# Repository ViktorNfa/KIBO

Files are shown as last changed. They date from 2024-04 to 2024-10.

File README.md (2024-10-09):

# KIBO Robot

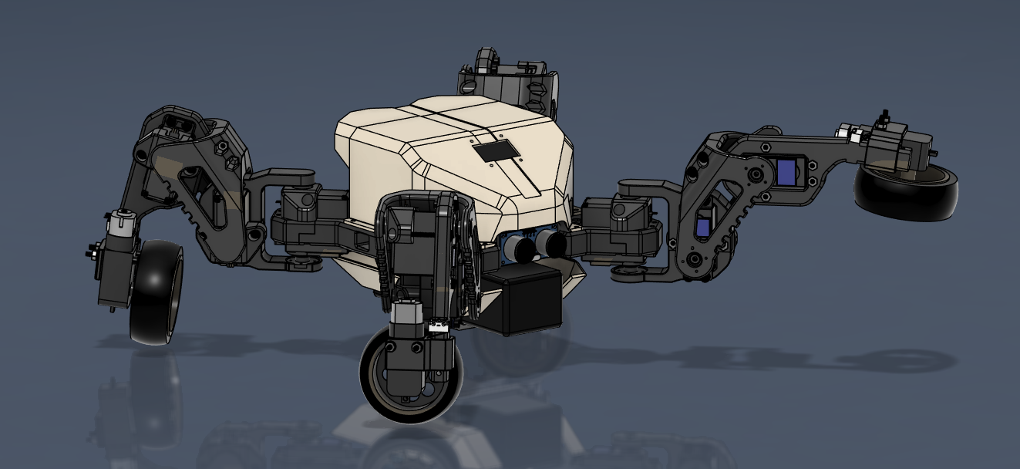
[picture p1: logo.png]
KIBO Logo


## Overview

KIBO is an advanced robotics platform designed for modularity and versatility. The project includes hardware designs, electronics, and firmware to control a multi-legged wheeled robotic system. The primary goal is to implement inverse kinematics (IK) walking modes and wheeled modes and gait optimization using Model Predictive Path Integral (MPPI) control through micro-ROS (uROS) in ESP32 and ROS2 nodes with C++.

## Table of Contents

1. [Getting Started](#getting-started)
2. [Features](#features)
3. [Hardware Overview](#hardware-overview)
   - [CAD Files](#cad-files)
   - [Electronics](#electronics)
4. [Software Overview](#software-overview)
   - [ESP32 Firmware](#esp32-firmware)
   - [ROS2 Nodes](#ros2-nodes)
   - [Gait Optimization with MPPI](#gait-optimization-with-mppi)
5. [Installation and Setup](#installation-and-setup)
6. [Usage](#usage)
7. [Contributing](#contributing)
8. [License](#license)
9. [Acknowledgments](#acknowledgments)

## Getting Started

This project is intended for researchers, hobbyists, and developers interested in robotics. To get started with KIBO:

1. Clone this repository.
2. Set up the hardware following the instructions in the [Hardware Overview](#hardware-overview) section.
3. Flash the ESP32 with the firmware provided in the [ESP32 Firmware](#esp32-firmware) section.
4. Configure and run the ROS2 nodes as described in the [ROS2 Nodes](#ros2-nodes) section.

## Features

- **Inverse Kinematics (IK) Walking Modes**: Implement various walking gaits using IK.
- **Gait Optimization**: Optimize the robot's gait using Model Predictive Path Integral (MPPI) control.
- **Micro-ROS (uROS) Integration**: Utilize uROS for real-time communication between ESP32 and ROS2 nodes.
- **ESP32-based Control**: Leverage the ESP32 microcontroller for low-level control and sensor integration.

## Hardware Overview

### CAD Files

The `CAD` directory contains the STL files required to 3D print the robot's structural components. These include parts like the body frame, limbs, and armor:

- **Body Frame**: `Kibo frame.stl`, `Frame End Tip.stl`,`L298N Driver Spacer.stl`
- **Coxa Components**: `Coxa Left.stl`, `Coxa Right.stl`
- **Femur Components**:`Femur Right.stl`,`Femur Left.stl`
- **Tibia Components**: `Tibia.stl`, `Tibia Slider.stl`
- **Armor**: `Bottom Body Armor Left.stl`, `Bottom Body Armor Right.stl`, `Body Armor Spoiler.stl`, `Top Body Armor.stl`
- **Miscellaneous**: `Servo Back Plate.stl`, `Servo Bushing.stl`, `ring.stl`, `Battery holder.stl`

These components can be printed using any standard 3D printer. Ensure that you use durable materials like PLA+ or PETG for better structural integrity.

### Electronics

The `Electronics` directory contains the KiCad files for the KIBO V1 PCB, including:

- **Schematic**: `KIBO V1.kicad_sch`
- **PCB Layout**: `KIBO V1.kicad_pcb`
- **Manufacturing Files**: `KIBO_PCBFab.zip`

You can manufacture the PCB using the provided Gerber files or modify the design using KiCad.

#### Symbols and Footprints

This subdirectory includes additional component libraries for symbols and footprints used in the PCB design:

- ESP32-CAM
- GY-521 (IMU Sensor)
- HC-SR04 (Ultrasonic Sensor)

## Software Overview

### ESP32 Firmware

The ESP32 firmware is still to be developed, but test files can be located in the `Firmware/esp32_tests` directory for the ESP32 and the `Firmware/esp32_cam_tests` directory for the ESP32-CAM. This firmware is responsible for:

- Starting FreeRTOS and seting up the tasks and priorities.
- Managing sensors and actuators.
- Communicating with ROS2 nodes via micro-ROS (uROS).

#### Key Files:

- `platformio.ini`: Configuration file for PlatformIO.
- `src/main.cpp`: Main entry point for the ESP32 application.
- `include/camera_pins.h`: Header files, e.g., defining the camera's GPIO pins.

### ROS2 Nodes

The ROS2 nodes are designed to handle higher-level control and coordination. These nodes communicate with the ESP32 using uROS and handle tasks such as:

- High-level motion planning.
- Real-time data processing from the robot's sensors.
- Gait optimization using MPPI.

#### Planned Features:

The following planned features will be added to the `Simulation` directory.

- **Inverse Kinematics (IK) Implementation**: Calculate joint angles for desired end-effector positions.
- **Gait Optimization with MPPI**: Optimize walking gaits to enhance stability and energy efficiency.

### Gait Optimization with MPPI

MPPI (Model Predictive Path Integral) control is a powerful method for optimizing the robot's gait. It will be used to predict and adjust the robot's movements in real-time, ensuring smooth and stable walking patterns.

## Installation and Setup

### Prerequisites

- **PlatformIO**: Required for building and flashing the ESP32 firmware.
- **ROS2 Humble**: Recommended version of ROS2 for running the ROS2 nodes.
- **uROS Agent**: Necessary for communication between ESP32 and ROS2.

### Instructions

1. **ESP32 Firmware**:
   - Navigate to the `Firmware/esp32_tests` directory.
   - Install the necessary PlatformIO dependencies.
   - Build and upload the firmware to your ESP32 module.

2. **ROS2 Nodes**:
   - Set up a ROS2 workspace and clone this repository into the `src` directory.
   - Build the workspace using `colcon build`.
   - Launch the nodes using the provided launch files.

## Usage

1. Power on the KIBO robot.
2. Launch the ROS2 nodes on your PC.
3. The ESP32 will automatically start communicating with the ROS2 nodes.
4. Use the provided ROS2 interfaces to command the robot and monitor its state.

## Contributing

We welcome contributions to the KIBO project! If you have suggestions, bug reports, or want to contribute new features, please open an issue or submit a pull request.

### Guidelines

- Follow the existing coding style.
- Document your code thoroughly.
- Test your contributions before submitting.

## License

This project is licensed under the MIT License - see the [LICENSE](LICENSE) file for details.

## Acknowledgments

We would like to thank the open-source community for their valuable tools and libraries that made this project possible.

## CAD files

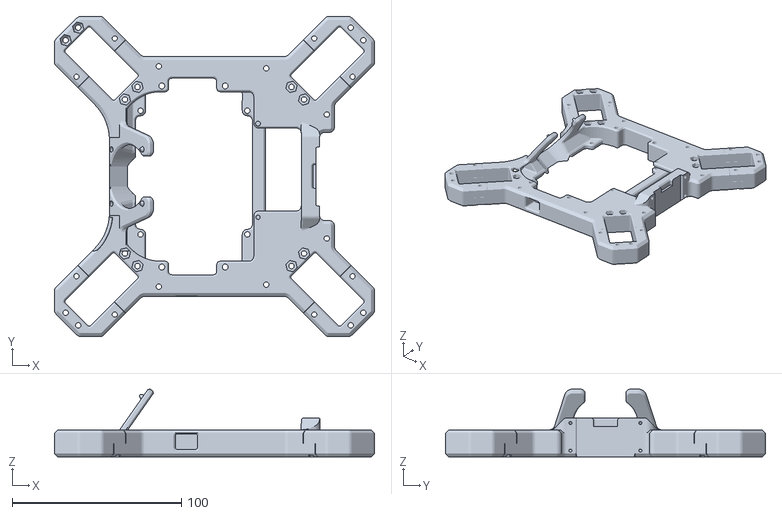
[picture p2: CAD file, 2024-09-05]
CAD/STL files/Kibo Frame.stl
188.9 x 188.9 x 40.0

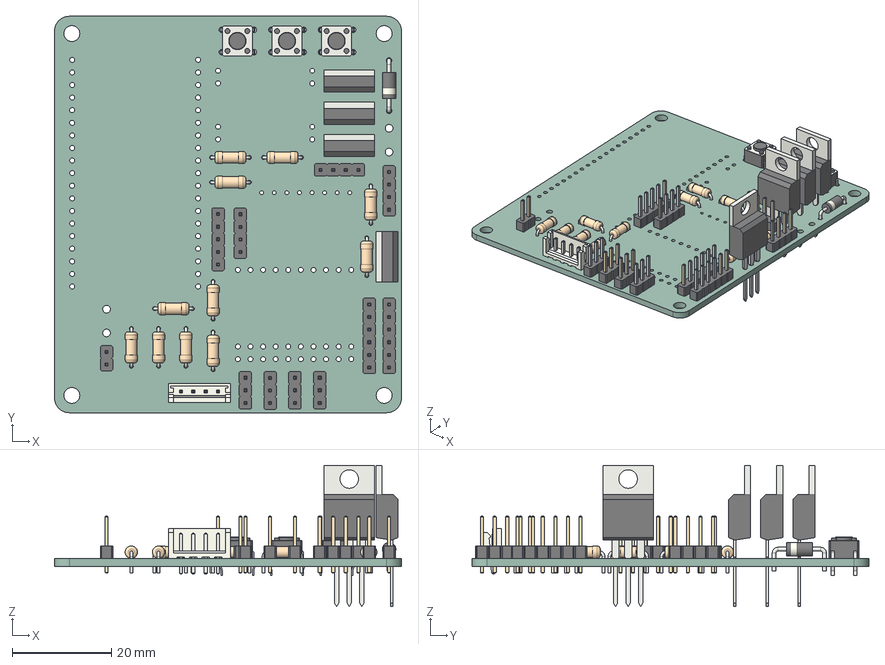
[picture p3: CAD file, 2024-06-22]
Electronics/KIBO V1/KIBO V1.step
70.0 x 80.0 x 28.5 mm
R_Axial_DIN0207_L63mm_D25mm_P762mm_Horizontal x 11
PinHeader_1x06_P254mm_Vertical x 2
TO-220-3_Vertical x 4
PinHeader_1x03_P254mm_Vertical x 4
PinHeader_1x05_P254mm_Vertical
D_DO-41_SOD81_P10.16mm_Horizontal
PinHeader_1x04_P254mm_Vertical x 3
PinHeader_1x02_P254mm_Vertical
SW_PUSH_6mm x 3
JST_B4B_EH_A
KIBO V1_PCB

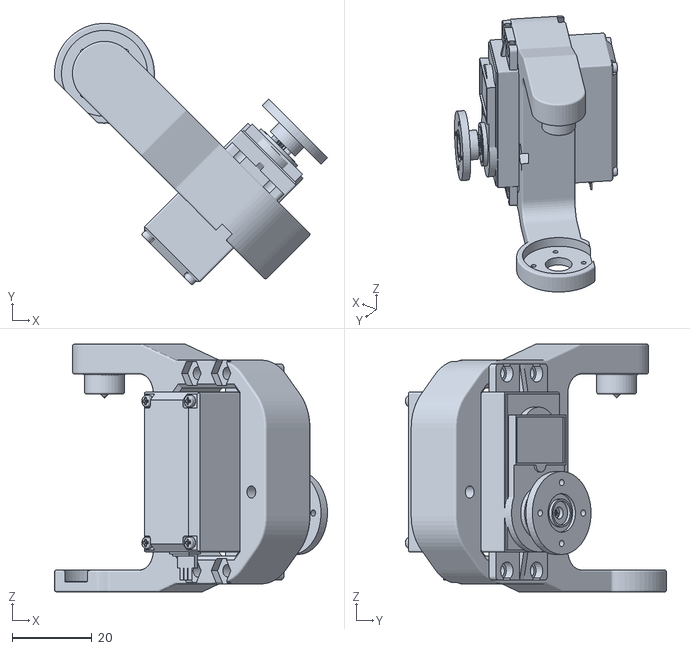
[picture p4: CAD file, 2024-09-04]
Simulation/URDF V1/urdf_description/meshes/Coxa_2_1.stl
68.3 x 65.4 x 62.0

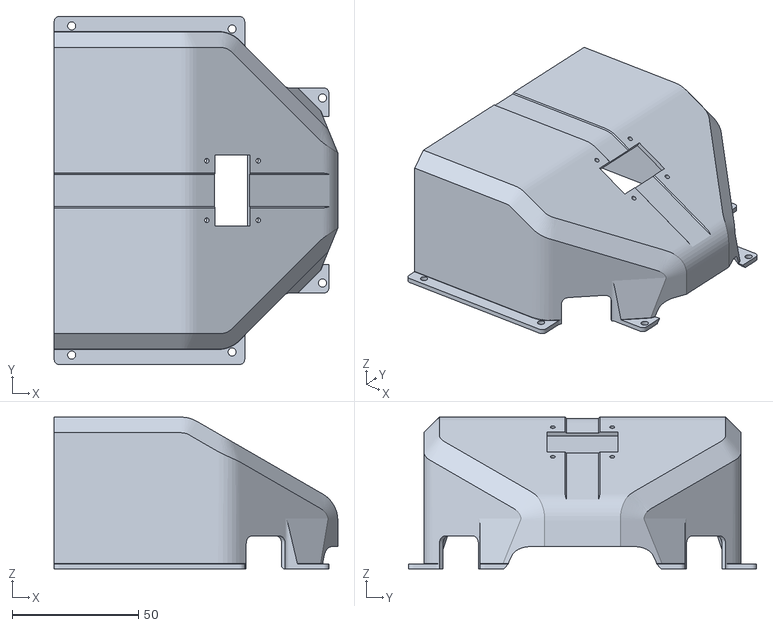
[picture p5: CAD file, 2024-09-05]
CAD/STL files/Top Body Armor.stl
112.2 x 137.6 x 60.0

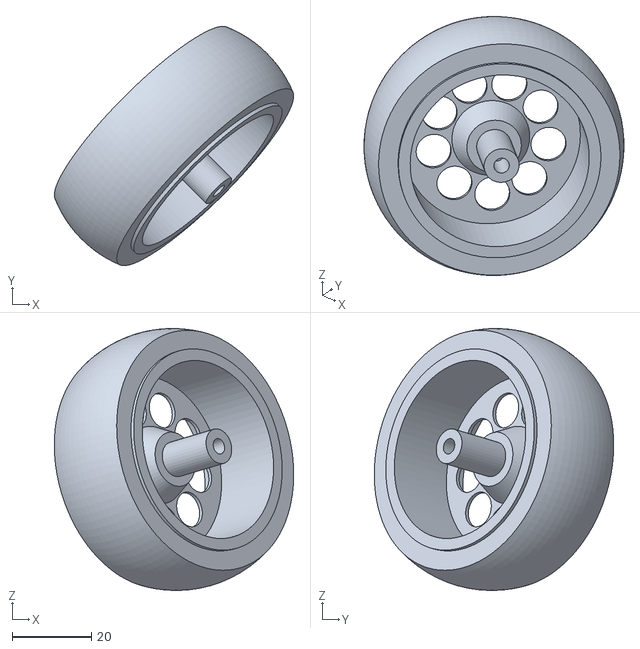
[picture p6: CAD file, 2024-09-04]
Simulation/URDF V1/urdf_description/meshes/Wheel_2_1.stl
60.5 x 60.5 x 66.2

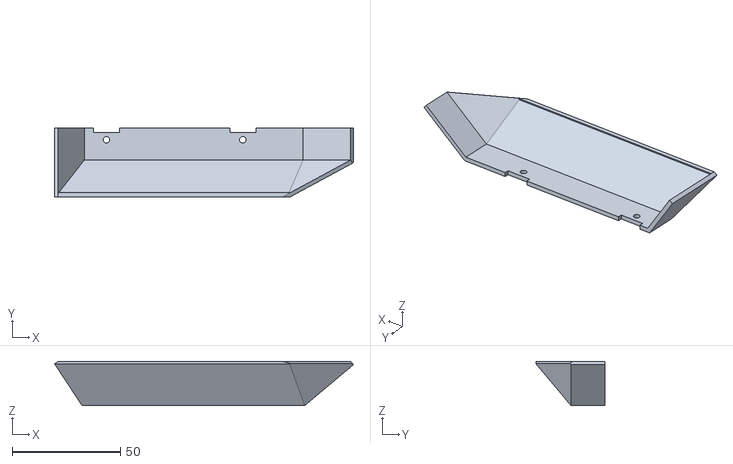
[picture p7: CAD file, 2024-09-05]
CAD/STL files/Bottom Body Armor Right.stl
138.2 x 31.7 x 20.4

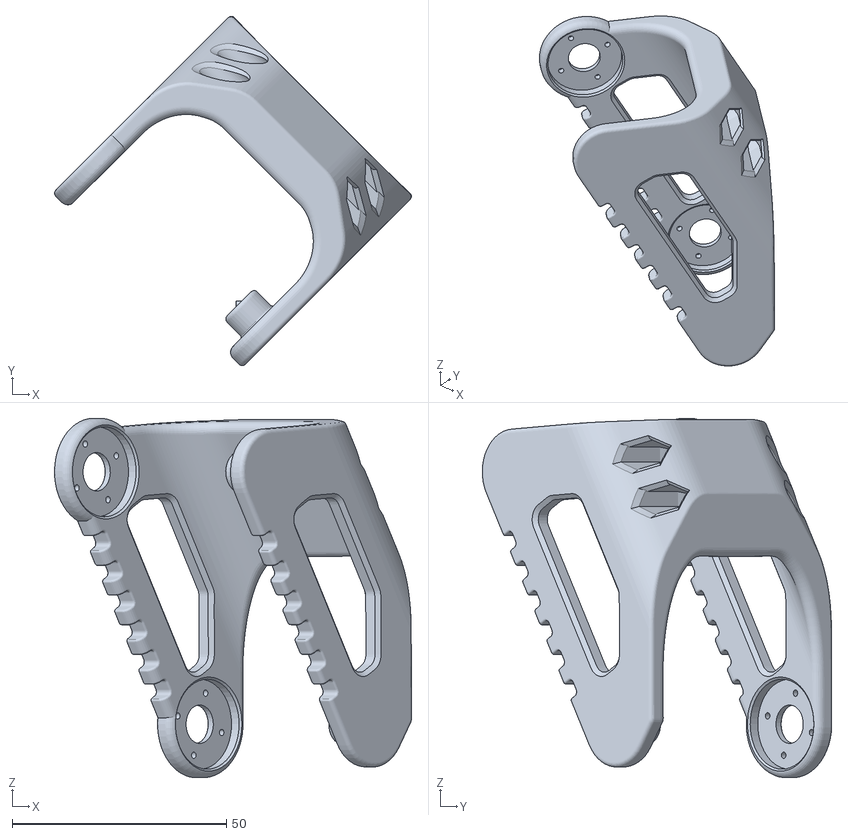
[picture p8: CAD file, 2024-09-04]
Simulation/URDF V1/urdf_description/meshes/Femur_3_1.stl
83.3 x 81.5 x 83.9

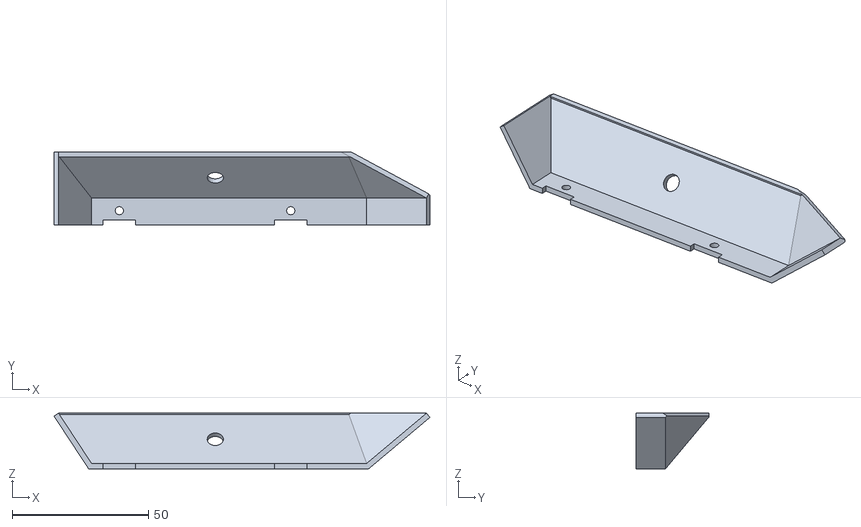
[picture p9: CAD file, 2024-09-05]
CAD/STL files/Bottom Body Armor Left.stl
138.2 x 27.0 x 20.4

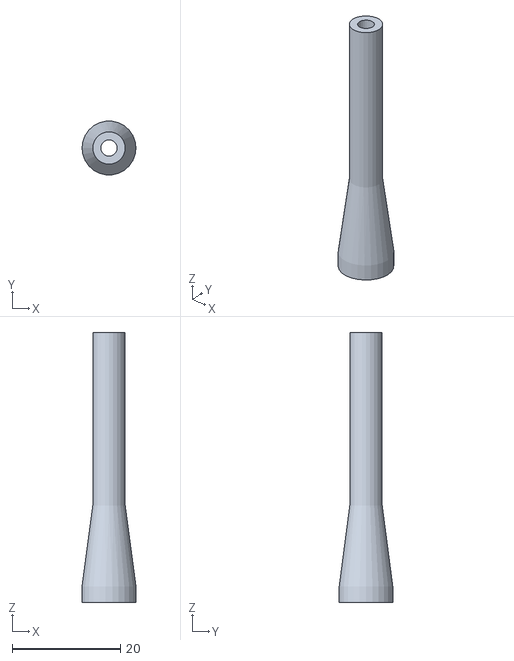
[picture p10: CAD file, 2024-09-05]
CAD/STL files/L298N Driver Spacer.stl
10.0 x 9.93 x 50.0

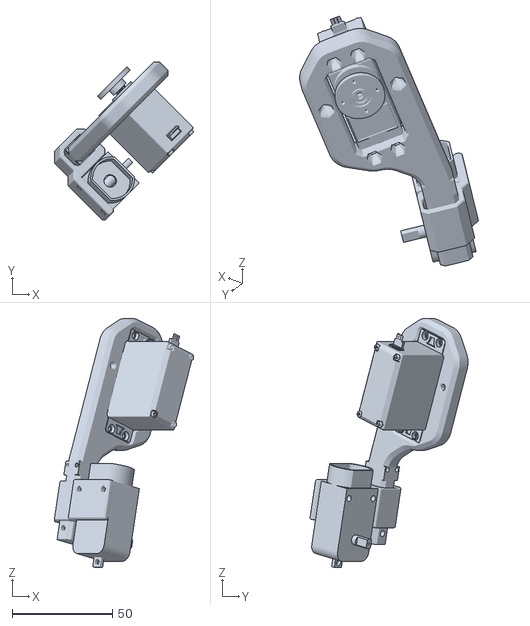
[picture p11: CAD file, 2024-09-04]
Simulation/URDF V1/urdf_description/meshes/Tibia_3_1.stl
69.5 x 78.7 x 124.0

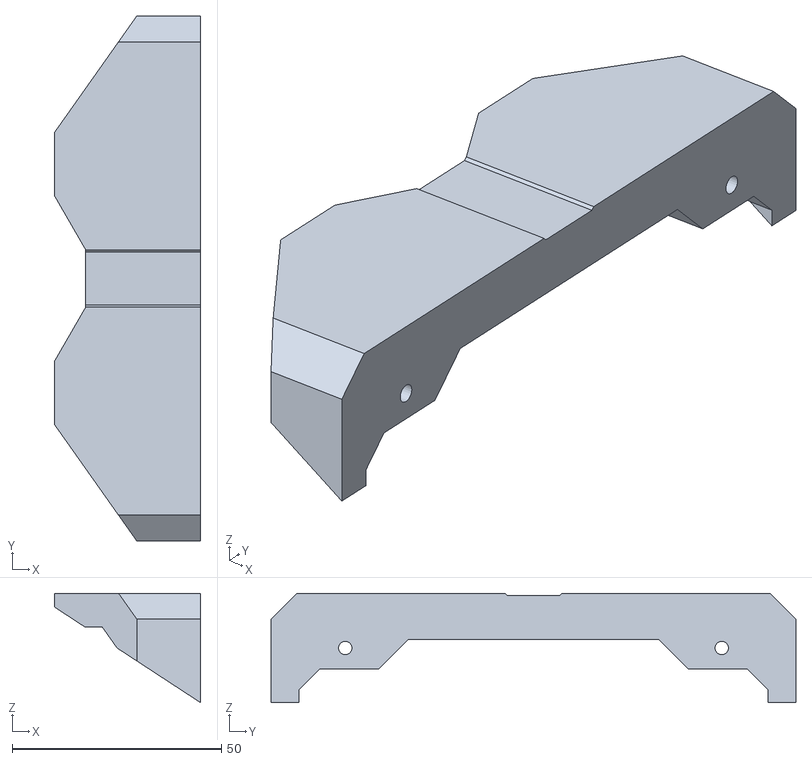
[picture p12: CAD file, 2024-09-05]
CAD/STL files/Body Armor Spoiler.stl
35.0 x 125.5 x 26.2

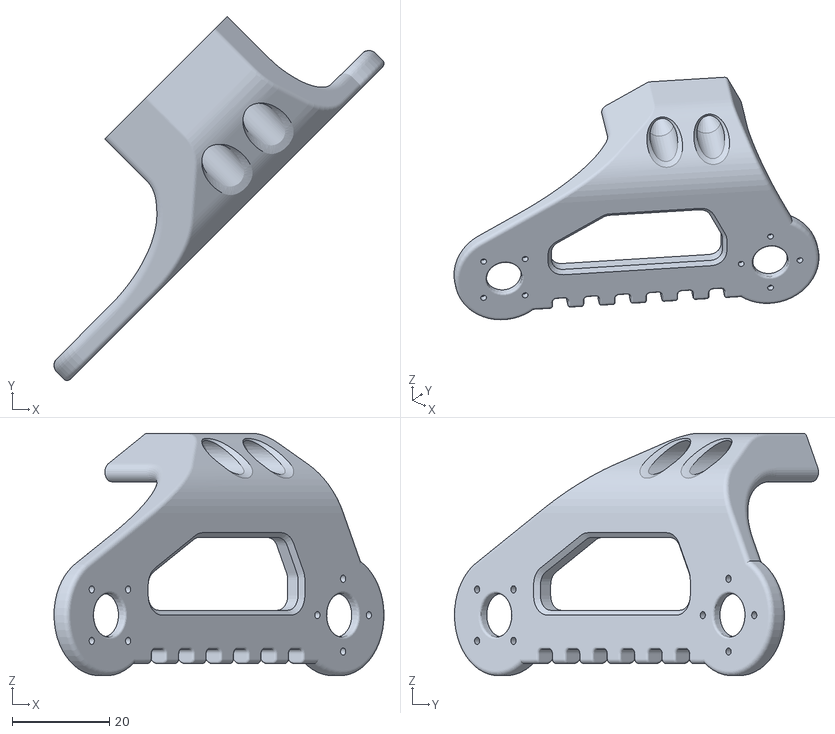
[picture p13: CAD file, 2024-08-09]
CAD/STL files/Femur Left.stl
68.0 x 75.1 x 50.0

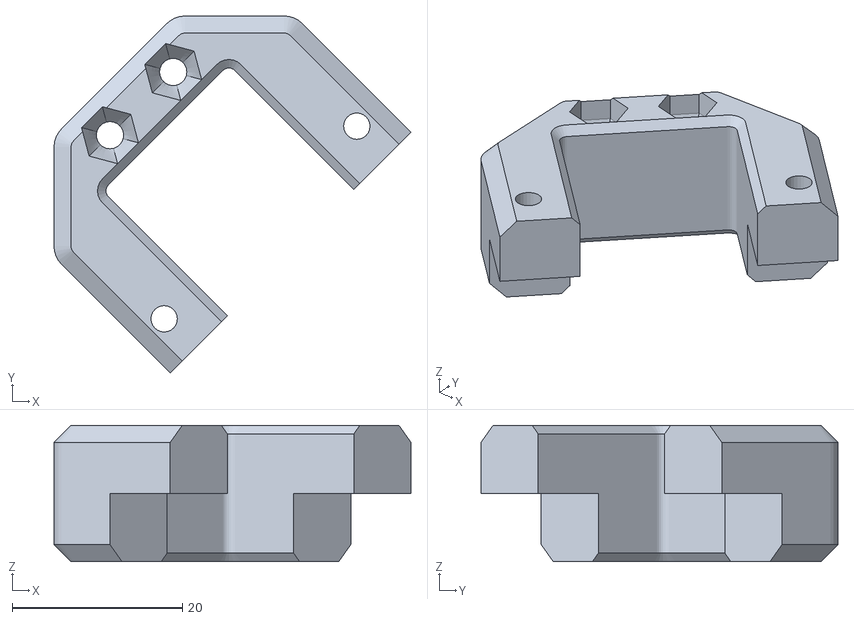
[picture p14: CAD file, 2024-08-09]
CAD/STL files/Frame End Tip.stl
41.9 x 41.9 x 16.0

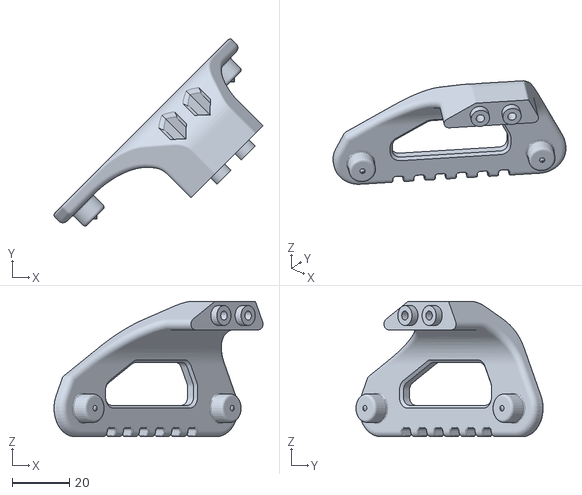
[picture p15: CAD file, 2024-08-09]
CAD/STL files/Femur Right.stl
73.3 x 65.6 x 47.5

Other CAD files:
Simulation/URDF V1/urdf_description/meshes/Coxa_4_1.stl
Simulation/URDF V1/urdf_description/meshes/Tibia_1_1.stl
Simulation/URDF V1/urdf_description/meshes/Wheel_3_1.stl
Simulation/URDF V1/urdf_description/meshes/Coxa_1_1.stl
CAD/STL files/Battery holder.stl
CAD/STL files/Coxa Left.stl
CAD/STL files/Coxa Right.stl
CAD/STL files/Servo Back Plate.stl
CAD/STL files/Servo Bushing.stl
CAD/STL files/Tibia Slider.stl
CAD/STL files/Tibia.stl
CAD/STL files/ring.stl
Simulation/URDF V1/urdf_description/meshes/Coxa_3_1.stl
Simulation/URDF V1/urdf_description/meshes/Femur_1_1.stl
Simulation/URDF V1/urdf_description/meshes/Femur_2_1.stl
Simulation/URDF V1/urdf_description/meshes/Femur_4_1.stl
Simulation/URDF V1/urdf_description/meshes/Tibia_2_1.stl
Simulation/URDF V1/urdf_description/meshes/Tibia_4_1.stl
Simulation/URDF V1/urdf_description/meshes/Wheel_1_1.stl
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

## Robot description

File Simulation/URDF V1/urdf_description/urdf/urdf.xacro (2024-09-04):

<?xml version="1.0" ?>
<robot name="urdf" xmlns:xacro="http://www.ros.org/wiki/xacro">

<xacro:include filename="$(find urdf_description)/urdf/materials.xacro" />
<xacro:include filename="$(find urdf_description)/urdf/urdf.trans" />
<link name="base_link">
  <inertial>
    <origin xyz="0.11409785556143377 0.2160923975106087 0.01801511377195926" rpy="0 0 0"/>
    <mass value="3.3158005563748603"/>
    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
  </inertial>
  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
</link>

<link name="Coxa_1_1">
  <inertial>
    <origin xyz="0.027257575572939674 0.028618177017522783 0.028058919678104678" rpy="0 0 0"/>
    <mass value="0.43696782867660955"/>
    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
  </inertial>
  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
</link>

<link name="Coxa_2_1">
  <inertial>
    <origin xyz="0.02725547522162386 -0.028619905086615507 0.025760165654032385" rpy="0 0 0"/>
    <mass value="0.4369178682176243"/>
    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
  </inertial>
  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
</link>

<link name="Coxa_3_1">
  <inertial>
    <origin xyz="-0.0272506183362799 -0.0286190490034907 0.028061981366867973" rpy="0 0 0"/>
    <mass value="0.43719830316904373"/>
    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
  </inertial>
  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
</link>

<link name="Coxa_4_1">
  <inertial>
    <origin xyz="-0.027255286358615242 0.028619539650880876 0.025760165652992714" rpy="0 0 0"/>
    <mass value="0.4369178682176243"/>
    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
  </inertial>
  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
</link>

<link name="Femur_1_1">
  <inertial>
    <origin xyz="-0.015520875498129971 0.023174915297567544 0.04337089287395373" rpy="0 0 0"/>
    <mass value="0.2737691041689558"/>
    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
  </inertial>
  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
</link>

<link name="Femur_2_1">
  <inertial>
    <origin xyz="-0.015520815420668382 -0.023174311368785117 0.04337086032823338" rpy="0 0 0"/>
    <mass value="0.27377009354481224"/>
    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
  </inertial>
  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
</link>

<link name="Femur_3_1">
  <inertial>
    <origin xyz="0.015521064361139213 -0.023174280733282426 0.043370892873953196" rpy="0 0 0"/>
    <mass value="0.2737691041689558"/>
    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
  </inertial>
  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
</link>

<link name="Femur_4_1">
  <inertial>
    <origin xyz="0.015521004283676032 0.023174945933051694 0.043370860327193235" rpy="0 0 0"/>
    <mass value="0.27377009354481224"/>
    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
  </inertial>
  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
</link>

<link name="Tibia_1_1">
  <inertial>
    <origin xyz="-0.004246971270543298 0.023418841979335414 -0.025715857225801428" rpy="0 0 0"/>
    <mass value="0.49843994930164737"/>
    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
  </inertial>
  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
</link>

<link name="Tibia_2_1">
  <inertial>
    <origin xyz="-0.004246850840331939 -0.02341835624538037 -0.025714852861407476" rpy="0 0 0"/>
    <mass value="0.49845955251063434"/>
    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
  </inertial>
  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
</link>

<link name="Tibia_3_1">
  <inertial>
    <origin xyz="0.004247160133553293 -0.023419207415050908 -0.02571585722580256" rpy="0 0 0"/>
    <mass value="0.49843994930164737"/>
    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
  </inertial>
  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
</link>

<link name="Tibia_4_1">
  <inertial>
    <origin xyz="0.004247039703339856 0.023417990809646072 -0.02571485286244969" rpy="0 0 0"/>
    <mass value="0.49845955251063434"/>
    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
  </inertial>
  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
</link>

<link name="Wheel_1_1">
  <inertial>
    <origin xyz="-0.011414826765339975 -0.01141481100347358 -0.003393428372262197" rpy="0 0 0"/>
    <mass value="0.3192676448711226"/>
    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
  </inertial>
  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
</link>

<link name="Wheel_2_1">
  <inertial>
    <origin xyz="-0.011415217559557156 0.011414836361964824 -0.0033934114162502797" rpy="0 0 0"/>
    <mass value="0.3192676448711226"/>
    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
  </inertial>
  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
</link>

<link name="Wheel_3_1">
  <inertial>
    <origin xyz="0.011415015628370679 0.011414445567735236 -0.003393428372272137" rpy="0 0 0"/>
    <mass value="0.3192676448711226"/>
    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
  </inertial>
  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
</link>

<link name="Wheel_4_1">
  <inertial>
    <origin xyz="0.011414406422587061 -0.01141520179768396 -0.003393411417283082" rpy="0 0 0"/>
    <mass value="0.3192676448711226"/>
    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
  </inertial>
  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
</link>

<joint name="Servo 1" type="revolute">
  <origin xyz="0.190178 0.289658 -0.0165" rpy="0 0 0"/>
  <parent link="base_link"/>
  <child link="Coxa_1_1"/>
  <axis xyz="0.0 -0.0 -1.0"/>
  <limit upper="1.570796" lower="-1.570796" effort="100" velocity="100"/>
</joint>

<joint name="Servo 4" type="revolute">
  <origin xyz="0.190178 0.141817 -0.0142" rpy="0 0 0"/>
  <parent link="base_link"/>
  <child link="Coxa_2_1"/>
  <axis xyz="0.0 -0.0 -1.0"/>
  <limit upper="1.570796" lower="-1.570796" effort="100" velocity="100"/>
</joint>

<joint name="Servo 7" type="revolute">
  <origin xyz="0.042337 0.141817 -0.0165" rpy="0 0 0"/>
  <parent link="base_link"/>
  <child link="Coxa_3_1"/>
  <axis xyz="0.0 -0.0 -1.0"/>
  <limit upper="1.570796" lower="-1.570796" effort="100" velocity="100"/>
</joint>

<joint name="Servo 10" type="revolute">
  <origin xyz="0.042337 0.289658 -0.0142" rpy="0 0 0"/>
  <parent link="base_link"/>
  <child link="Coxa_4_1"/>
  <axis xyz="0.0 -0.0 -1.0"/>
  <limit upper="1.570796" lower="-1.570796" effort="100" velocity="100"/>
</joint>

<joint name="Servo 2" type="revolute">
  <origin xyz="0.046846 0.015379 0.01725" rpy="0 0 0"/>
  <parent link="Coxa_1_1"/>
  <child link="Femur_1_1"/>
  <axis xyz="0.707107 -0.707107 0.0"/>
  <limit upper="0.0" lower="-3.141593" effort="100" velocity="100"/>
</joint>

<joint name="Servo 5" type="revolute">
  <origin xyz="0.046846 -0.01538 0.01495" rpy="0 0 0"/>
  <parent link="Coxa_2_1"/>
  <child link="Femur_2_1"/>
  <axis xyz="0.707107 0.707107 0.0"/>
  <limit upper="3.141593" lower="0.0" effort="100" velocity="100"/>
</joint>

<joint name="Servo 8" type="revolute">
  <origin xyz="-0.046846 -0.01538 0.01725" rpy="0 0 0"/>
  <parent link="Coxa_3_1"/>
  <child link="Femur_3_1"/>
  <axis xyz="-0.707107 0.707107 -0.0"/>
  <limit upper="0.0" lower="-3.141593" effort="100" velocity="100"/>
</joint>

<joint name="Servo 11" type="revolute">
  <origin xyz="-0.046846 0.015379 0.01495" rpy="0 0 0"/>
  <parent link="Coxa_4_1"/>
  <child link="Femur_4_1"/>
  <axis xyz="-0.707107 -0.707107 0.0"/>
  <limit upper="3.141593" lower="0.0" effort="100" velocity="100"/>
</joint>

<joint name="Servo 3" type="revolute">
  <origin xyz="0.024041 0.024042 0.05889" rpy="0 0 0"/>
  <parent link="Femur_1_1"/>
  <child link="Tibia_1_1"/>
  <axis xyz="-0.707107 0.707107 -0.0"/>
  <limit upper="0.0" lower="-2.96706" effort="100" velocity="100"/>
</joint>

<joint name="Servo 6" type="revolute">
  <origin xyz="0.024041 -0.024041 0.05889" rpy="0 0 0"/>
  <parent link="Femur_2_1"/>
  <child link="Tibia_2_1"/>
  <axis xyz="0.707107 0.707107 0.0"/>
  <limit upper="0.0" lower="-2.96706" effort="100" velocity="100"/>
</joint>

<joint name="Servo 9" type="revolute">
  <origin xyz="-0.024041 -0.024041 0.05889" rpy="0 0 0"/>
  <parent link="Femur_3_1"/>
  <child link="Tibia_3_1"/>
  <axis xyz="0.707107 -0.707107 0.0"/>
  <limit upper="0.0" lower="-2.96706" effort="100" velocity="100"/>
</joint>

<joint name="Servo 12" type="revolute">
  <origin xyz="-0.024041 0.024042 0.05889" rpy="0 0 0"/>
  <parent link="Femur_4_1"/>
  <child link="Tibia_4_1"/>
  <axis xyz="-0.707107 -0.707107 0.0"/>
  <limit upper="0.0" lower="-2.96706" effort="100" velocity="100"/>
</joint>

<joint name="Wheel 1" type="continuous">
  <origin xyz="0.000143 0.045468 -0.086158" rpy="0 0 0"/>
  <parent link="Tibia_1_1"/>
  <child link="Wheel_1_1"/>
  <axis xyz="0.691987 0.691987 0.20569"/>
</joint>

<joint name="Wheel 2" type="continuous">
  <origin xyz="-0.000341 -0.044984 -0.086302" rpy="0 0 0"/>
  <parent link="Tibia_2_1"/>
  <child link="Wheel_2_1"/>
  <axis xyz="0.691987 -0.691987 0.20569"/>
</joint>

<joint name="Wheel 3" type="continuous">
  <origin xyz="-0.000143 -0.045468 -0.086158" rpy="0 0 0"/>
  <parent link="Tibia_3_1"/>
  <child link="Wheel_3_1"/>
  <axis xyz="-0.691987 -0.691987 0.20569"/>
</joint>

<joint name="Wheel 4" type="continuous">
  <origin xyz="0.000342 0.044984 -0.086302" rpy="0 0 0"/>
  <parent link="Tibia_4_1"/>
  <child link="Wheel_4_1"/>
  <axis xyz="-0.691987 0.691987 0.20569"/>
</joint>

</robot>

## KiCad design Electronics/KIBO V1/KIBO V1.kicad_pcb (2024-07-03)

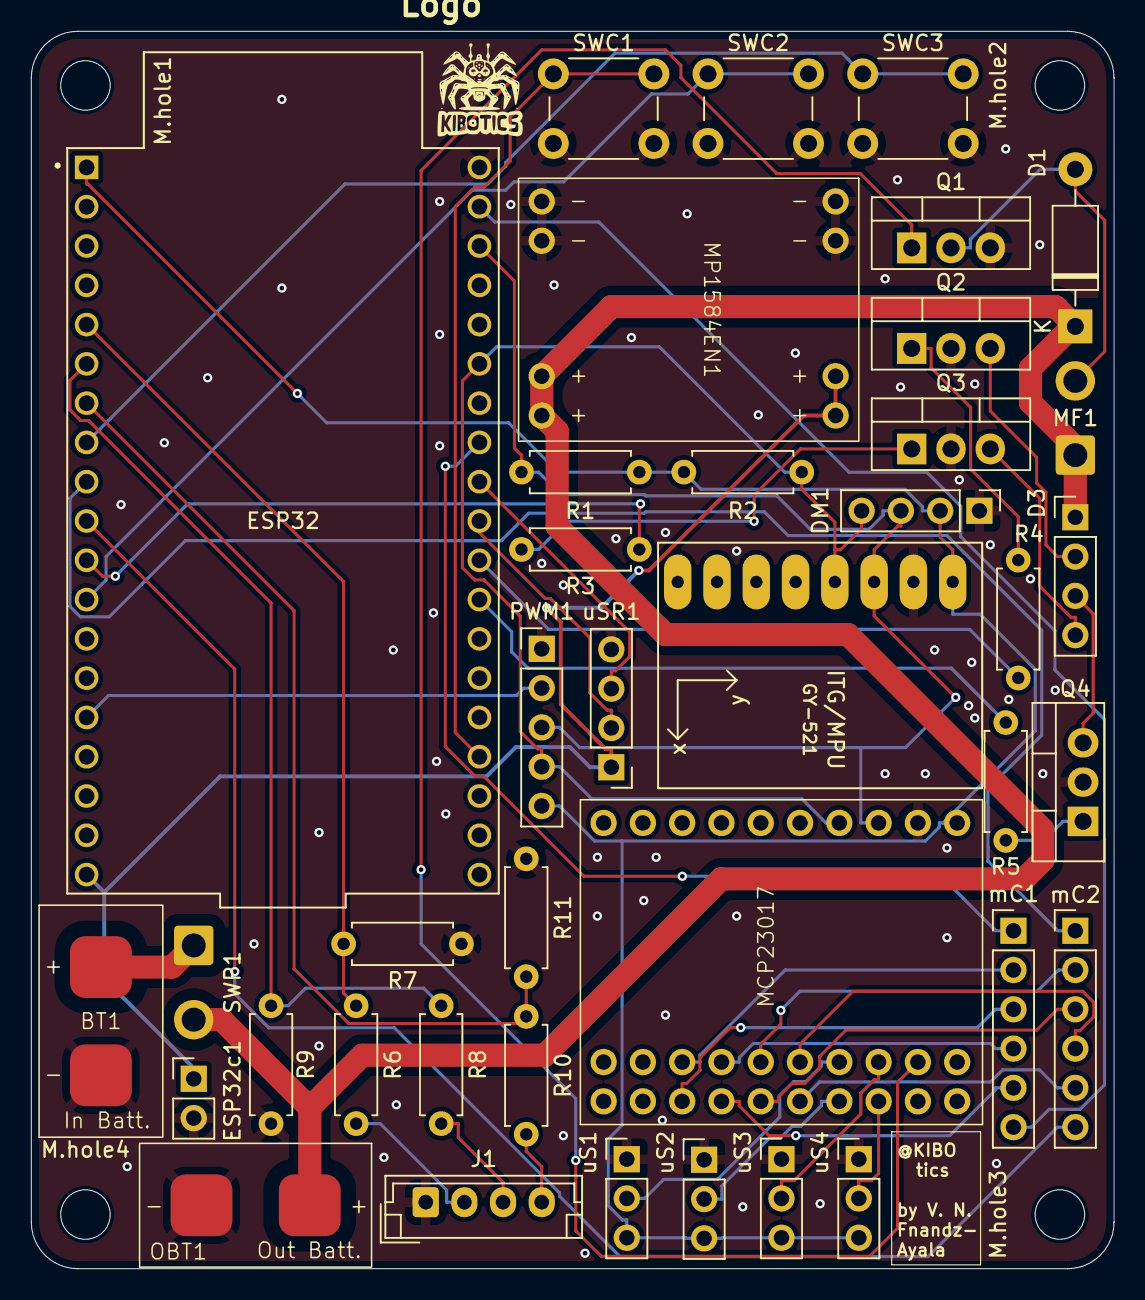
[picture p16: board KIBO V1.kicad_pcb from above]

Board: 2 copper layers, 70.0 x 80.0 mm, 44 parts (0 on the bottom side), 46 nets.

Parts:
BT1: 11V1; 2xBatterty_Wire_Pads
D1: 1N4001; D_DO-41_SOD81_P10.16mm_Horizontal
D3: LED_AGRB; PinHeader_1x04_P2.54mm_Vertical
DM1: DM-OLED; PinHeader_1x04_P2.54mm_Vertical
ESP32: ESP32-DEVKITC; MODULE_ESP32-DEVKITC
ESP32c1: ESP32-CAM; PinHeader_1x02_P2.54mm_Vertical
GY-521: GY-521
J1: Conn_01x04; JST_EH_B4B-EH-A_1x04_P2.50mm_Vertical
Logo: LOGO
M.hole1, M.hole2, M.hole3, M.hole4: MountingHole_3.2mm_M3
MCP23017: PortExt; MCP23017
MF1: Fan; SolderWire-0.75sqmm_1x02_P4.8mm_D1.25mm_OD2.3mm
MP1584EN1: VoltConv; MP-1584EN
OBT1: UBEC; 2xBatterty_Wire_Pads
PWM1: PWM; PinHeader_1x05_P2.54mm_Vertical
Q1, Q2, Q3, Q4: TIP120; TO-220-3_Vertical
R1, R2: 4k7; R_Axial_DIN0207_L6.3mm_D2.5mm_P7.62mm_Horizontal
R3, R4, R5, R8: 1k; R_Axial_DIN0207_L6.3mm_D2.5mm_P7.62mm_Horizontal
R6, R10: 5k6; R_Axial_DIN0207_L6.3mm_D2.5mm_P7.62mm_Horizontal
R7: 22k; R_Axial_DIN0207_L6.3mm_D2.5mm_P7.62mm_Horizontal
R9: 680; R_Axial_DIN0207_L6.3mm_D2.5mm_P7.62mm_Horizontal
R11: 2k; R_Axial_DIN0207_L6.3mm_D2.5mm_P7.62mm_Horizontal
SWC1, SWC2, SWC3: SW_Push; SW_PUSH_6mm
SWP1: SWP; SolderWire-0.75sqmm_1x02_P4.8mm_D1.25mm_OD2.3mm
mC1, mC2: MotorDriver; PinHeader_1x06_P2.54mm_Vertical
uS1, uS2, uS3, uS4: uSwitch; PinHeader_1x03_P2.54mm_Vertical
uSR1: HC-SR04; PinHeader_1x04_P2.54mm_Vertical

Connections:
+3V3: DM1.2 (VCC_IN), ESP32.1 (3V3), GY-521.VCC, MCP23017.10 (VCC), PWM1.5 (VCC), R1.1, R2.1, uS1.3 (NO), uS2.3 (NO), uS3.3 (NO), uS4.3 (NO)
+5V: ESP32.19 (EXT_5V), ESP32c1.1 (5V), MP1584EN1.7 (OUT+), MP1584EN1.8 (OUT+), uSR1.1 (VCC)
+11V1: D1.1 (K), D3.1 (A), MF1.1 (+), MP1584EN1.3 (IN+), MP1584EN1.4 (IN+), OBT1.1 (IN+), SWP1.2 (B)
/B: ESP32.11 (IO27), R3.1
/CLL1: ESP32.5 (IO34), R6.1, R7.2
/CLL2: ESP32.6 (IO35), R8.1, R9.2
/CLL3: ESP32.7 (IO32), R10.1, R11.2
/ECHO: ESP32.30 (IO18), uSR1.3 (ECHO)
/FAN: MCP23017.27 (B6), Q1.1 (B)
/G: ESP32.28 (IO17), R4.1
/M1EN: ESP32.31 (IO19), mC1.1 (ENA)
/M1IN1: MCP23017.15 (B0), mC1.2 (IN1)
/M1IN2: MCP23017.16 (A0), mC1.3 (IN2)
/M2EN: ESP32.37 (IO23), mC1.6 (ENB)
/M2IN1: MCP23017.17 (B1), mC1.4 (IN3)
/M2IN2: MCP23017.18 (A1), mC1.5 (IN4)
/M3EN: ESP32.9 (IO25), mC2.1 (ENA)
/M3IN1: MCP23017.19 (B2), mC2.2 (IN1)
/M3IN2: MCP23017.20 (A2), mC2.3 (IN2)
/M4EN: ESP32.10 (IO26), mC2.6 (ENB)
/M4IN1: MCP23017.21 (B3), mC2.4 (IN3)
/M4IN2: MCP23017.22 (A3), mC2.5 (IN4)
/OE: ESP32.15 (IO13), PWM1.2 (OE)
/R: ESP32.27 (IO16), R5.1
/S1: MCP23017.23 (B4), uS1.2 (COM)
/S2: MCP23017.24 (A4), uS2.2 (COM)
/S3: MCP23017.25 (B5), uS3.2 (COM)
/S4: MCP23017.26 (A5), uS4.2 (COM)
/SCL: DM1.3 (SCL), ESP32.36 (IO22), GY-521.SCL, MCP23017.8 (SCK), PWM1.3 (SCL), R1.2
/SDA: DM1.4 (SDA), ESP32.33 (IO21), GY-521.SDA, MCP23017.7 (SDA), PWM1.4 (SDA), R2.2
/SW1: ESP32.23 (IO15), SWC1.1
/SW2: ESP32.12 (IO14), SWC2.1
/SW3: ESP32.8 (IO33), SWC3.1
/TRIG: ESP32.29 (IO5), uSR1.2 (TRIG)
GND: BT1.2 (-), DM1.1 (GND), ESP32.38 (GND3), ESP32c1.2 (GND@3), GY-521.GND, J1.1, MCP23017.9 (GND), MP1584EN1.1 (IN-), MP1584EN1.2 (IN-), MP1584EN1.5 (OUT-), MP1584EN1.6 (OUT-), OBT1.2 (IN-), PWM1.1 (GND), Q1.3 (E), Q2.2 (C), Q3.2 (C), Q4.2 (C), R7.1, R9.1, R11.1, SWC1.2, SWC2.2, SWC3.2, uS1.1 (NC), uS2.1 (NC), uS3.1 (NC), uS4.1 (NC), uSR1.4 (GND)
unnamed: BT1.1 (+), SWP1.1 (A)
unnamed: D1.2 (A), MF1.2 (-), Q1.2 (C)
unnamed: D3.4 (BK), Q3.3 (E)
unnamed: D3.2 (GK), Q2.3 (E)
unnamed: D3.3 (RK), Q4.3 (E)
unnamed: J1.2, R6.2
unnamed: J1.3, R8.2
unnamed: J1.4, R10.2
unnamed: Q2.1 (B), R4.2
unnamed: Q3.1 (B), R3.2
unnamed: Q4.1 (B), R5.2

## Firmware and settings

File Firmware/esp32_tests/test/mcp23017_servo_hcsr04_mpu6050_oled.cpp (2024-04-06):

// Include Wire Library for I2C
#include <Wire.h>
 
// Include Adafruit PCA9685 Servo Library
#include <Adafruit_PWMServoDriver.h>

// Include Adafruit MPU6050 IMU and SSD1306 OLED Library
#include <Adafruit_MPU6050.h>
#include <Adafruit_SSD1306.h>
#include <Adafruit_Sensor.h>

// Include Adafruit MCP23X17 Library
#include <Adafruit_MCP23X17.h>
 
// Creat object to represent PCA9685 at default I2C address
Adafruit_PWMServoDriver pca9685 = Adafruit_PWMServoDriver(0x40);

// Define maximum and minimum number of "ticks" for the servo motors
// Range from 0 to 4095
// This determines the pulse width
 
#define SERVOMIN  80  // Minimum value
#define SERVOMAX  600  // Maximum value
 
// Define servo motor connections (expand as required)
#define SER0  0   //Servo Motor 0 on connector 0
#define SER1  1  //Servo Motor 1 on connector 12
 
// Variables for Servo Motor positions (expand as required)
int pwm0;
int pwm1;

// Variables for Servo Motor positions
int posDegrees = 0;

// Creat object to represent MPU6050 and SSD1306
Adafruit_MPU6050 mpu;
Adafruit_SSD1306 display = Adafruit_SSD1306(128, 64, &Wire);

// Variables for HC-SR04 Ultrasonic Sensor
const int trigPin = 5;
const int echoPin = 18;
#define SOUND_SPEED 0.034 //define sound speed in cm/uS
#define CM_TO_INCH 0.393701
long duration;
float distanceCm;
float distanceInch;

// Objects and variables for MCP23X17
Adafruit_MCP23X17 mcp;
#define LIMIT_SWITCH 12     // MCP23XXX pin LIMIT_SWITCH is connected to
 
void setup() {
  // Serial monitor setup
  Serial.begin(115200);
  // while (!Serial);
  Serial.println("MPU6050+OLED+HC-SR04+PCA9685+MCP23X17 with limit switch demo");

  // Initialize PCA9685
  pca9685.begin();
 
  // Set PWM Frequency to 50Hz
  pca9685.setPWMFreq(50);

  pinMode(trigPin, OUTPUT); // Sets the trigPin as an Output
  pinMode(echoPin, INPUT); // Sets the echoPin as an Input

  if (!mpu.begin()) {
    Serial.println("Sensor init failed");
    while (1)
      yield();
  }
  Serial.println("Found a MPU-6050 sensor");

  // SSD1306_SWITCHCAPVCC = generate display voltage from 3.3V internally
  if (!display.begin(SSD1306_SWITCHCAPVCC, 0x3C)) { // Address 0x3C for 128x64
    Serial.println(F("SSD1306 allocation failed"));
    for (;;)
      ; // Don't proceed, loop forever
  }
  display.display();
  delay(500); // Pause for 2 seconds
  display.setTextSize(1);
  display.setTextColor(WHITE);
  display.setRotation(0);

  if (!mcp.begin_I2C()) {
    Serial.println("Error with MCP23X17.");
    while (1);
  }
  // configure pin for output
  mcp.pinMode(LIMIT_SWITCH, INPUT);
}
 
void loop() {
  // Determine PWM pulse width
  pwm0 = map(posDegrees, 0, 180, SERVOMIN, SERVOMAX);
  pwm1 = map(posDegrees, 0, 180, SERVOMIN, SERVOMAX);
  // Write to PCA9685
  pca9685.setPWM(SER0, 0, pwm0);
  pca9685.setPWM(SER1, 0, pwm1);
  // Print to serial monitor
  Serial.print("Motor 0 & 1 = ");
  Serial.println(posDegrees);
  // Increment posDegrees by 1 if it is less than 180, otherwise reset to 0
  if (posDegrees == 180) 
    posDegrees = 0;
  else
    posDegrees++;

  // Clears the trigPin
  digitalWrite(trigPin, LOW);
  delayMicroseconds(2);
  // Sets the trigPin on HIGH state for 10 micro seconds
  digitalWrite(trigPin, HIGH);
  delayMicroseconds(10);
  digitalWrite(trigPin, LOW);
  
  // Reads the echoPin, returns the sound wave travel time in microseconds
  duration = pulseIn(echoPin, HIGH);
  
  // Calculate the distance
  distanceCm = duration * SOUND_SPEED/2;
  
  // Convert to inches
  distanceInch = distanceCm * CM_TO_INCH;

  sensors_event_t a, g, temp;
  mpu.getEvent(&a, &g, &temp);

  display.clearDisplay();
  display.setCursor(0, 0);

  Serial.print("Accelerometer ");
  Serial.print("X: ");
  Serial.print(a.acceleration.x, 1);
  Serial.print(" m/s^2, ");
  Serial.print("Y: ");
  Serial.print(a.acceleration.y, 1);
  Serial.print(" m/s^2, ");
  Serial.print("Z: ");
  Serial.print(a.acceleration.z, 1);
  Serial.println(" m/s^2");

  display.println("Accelerometer - m/s^2");
  display.print(a.acceleration.x, 1);
  display.print(", ");
  display.print(a.acceleration.y, 1);
  display.print(", ");
  display.print(a.acceleration.z, 1);
  display.println("");

  Serial.print("Gyroscope ");
  Serial.print("X: ");
  Serial.print(g.gyro.x, 1);
  Serial.print(" rps, ");
  Serial.print("Y: ");
  Serial.print(g.gyro.y, 1);
  Serial.print(" rps, ");
  Serial.print("Z: ");
  Serial.print(g.gyro.z, 1);
  Serial.println(" rps");

  display.println("Gyroscope - rps");
  display.print(g.gyro.x, 1);
  display.print(", ");
  display.print(g.gyro.y, 1);
  display.print(", ");
  display.print(g.gyro.z, 1);
  display.println("");

  // Prints the distance in the Serial Monitor
  Serial.print("Distance (cm): ");
  Serial.println(distanceCm);
  Serial.print("Distance (inch): ");
  Serial.println(distanceInch);

  //Display distance in cm
  display.println("Distance: ");
  display.print(distanceCm);
  display.print(" cm");

  display.display();

  if (mcp.digitalRead(LIMIT_SWITCH) == HIGH)
  {
    Serial.println("Activated!");
  }
  else
  {
    Serial.println("Not activated.");
  }

  delay(100);
}

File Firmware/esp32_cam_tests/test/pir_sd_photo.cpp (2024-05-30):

/*********
  Rui Santos
  Complete project details at https://RandomNerdTutorials.com/esp32-cam-pir-motion-detector-photo-capture/
 
  IMPORTANT!!!
   - Select Board "AI Thinker ESP32-CAM"
   - GPIO 0 must be connected to GND to upload a sketch
   - After connecting GPIO 0 to GND, press the ESP32-CAM on-board RESET button to put your board in flashing mode
 
  Permission is hereby granted, free of charge, to any person obtaining a copy
  of this software and associated documentation files.
  The above copyright notice and this permission notice shall be included in all
  copies or substantial portions of the Software.
*********/
 
#include "esp_camera.h"
#include "Arduino.h"
#include "FS.h"                // SD Card ESP32
#include "SD_MMC.h"            // SD Card ESP32
#include "soc/soc.h"           // Disable brownour problems
#include "soc/rtc_cntl_reg.h"  // Disable brownour problems
#include "driver/rtc_io.h"
#include <EEPROM.h>            // read and write from flash memory
// define the number of bytes you want to access
#define EEPROM_SIZE 1
 
RTC_DATA_ATTR int bootCount = 0;

// Pin definition for CAMERA_MODEL_AI_THINKER
#define PWDN_GPIO_NUM     32
#define RESET_GPIO_NUM    -1
#define XCLK_GPIO_NUM      0
#define SIOD_GPIO_NUM     26
#define SIOC_GPIO_NUM     27
#define Y9_GPIO_NUM       35
#define Y8_GPIO_NUM       34
#define Y7_GPIO_NUM       39
#define Y6_GPIO_NUM       36
#define Y5_GPIO_NUM       21
#define Y4_GPIO_NUM       19
#define Y3_GPIO_NUM       18
#define Y2_GPIO_NUM        5
#define VSYNC_GPIO_NUM    25
#define HREF_GPIO_NUM     23
#define PCLK_GPIO_NUM     22
 
int pictureNumber = 0;
  
void setup() {
  WRITE_PERI_REG(RTC_CNTL_BROWN_OUT_REG, 0); //disable brownout detector
  Serial.begin(115200);
 
  Serial.setDebugOutput(true);
 
  camera_config_t config;
  config.ledc_channel = LEDC_CHANNEL_0;
  config.ledc_timer = LEDC_TIMER_0;
  config.pin_d0 = Y2_GPIO_NUM;
  config.pin_d1 = Y3_GPIO_NUM;
  config.pin_d2 = Y4_GPIO_NUM;
  config.pin_d3 = Y5_GPIO_NUM;
  config.pin_d4 = Y6_GPIO_NUM;
  config.pin_d5 = Y7_GPIO_NUM;
  config.pin_d6 = Y8_GPIO_NUM;
  config.pin_d7 = Y9_GPIO_NUM;
  config.pin_xclk = XCLK_GPIO_NUM;
  config.pin_pclk = PCLK_GPIO_NUM;
  config.pin_vsync = VSYNC_GPIO_NUM;
  config.pin_href = HREF_GPIO_NUM;
  config.pin_sscb_sda = SIOD_GPIO_NUM;
  config.pin_sscb_scl = SIOC_GPIO_NUM;
  config.pin_pwdn = PWDN_GPIO_NUM;
  config.pin_reset = RESET_GPIO_NUM;
  config.xclk_freq_hz = 20000000;
  config.pixel_format = PIXFORMAT_JPEG;
  
  pinMode(4, INPUT);
  digitalWrite(4, LOW);
  rtc_gpio_hold_dis(GPIO_NUM_4);
 
  if(psramFound()){
    config.frame_size = FRAMESIZE_UXGA; // FRAMESIZE_ + QVGA|CIF|VGA|SVGA|XGA|SXGA|UXGA
    config.jpeg_quality = 10;
    config.fb_count = 2;
  } else {
    config.frame_size = FRAMESIZE_SVGA;
    config.jpeg_quality = 12;
    config.fb_count = 1;
  }
 
  // Init Camera
  esp_err_t err = esp_camera_init(&config);
  if (err != ESP_OK) {
    Serial.printf("Camera init failed with error 0x%x", err);
    return;
  }
 
  Serial.println("Starting SD Card");
 
  delay(500);
  if(!SD_MMC.begin()){
    Serial.println("SD Card Mount Failed");
    //return;
  }
 
  uint8_t cardType = SD_MMC.cardType();
  if(cardType == CARD_NONE){
    Serial.println("No SD Card attached");
    return;
  }
   
  camera_fb_t * fb = NULL;
 
  // Take Picture with Camera
  fb = esp_camera_fb_get();  
  if(!fb) {
    Serial.println("Camera capture failed");
    return;
  }
  // initialize EEPROM with predefined size
  EEPROM.begin(EEPROM_SIZE);
  pictureNumber = EEPROM.read(0) + 1;
 
  // Path where new picture will be saved in SD Card
  String path = "/picture" + String(pictureNumber) +".jpg";
 
  fs::FS &fs = SD_MMC;
  Serial.printf("Picture file name: %s\n", path.c_str());
 
  File file = fs.open(path.c_str(), FILE_WRITE);
  if(!file){
    Serial.println("Failed to open file in writing mode");
  }
  else {
    file.write(fb->buf, fb->len); // payload (image), payload length
    Serial.printf("Saved file to path: %s\n", path.c_str());
    EEPROM.write(0, pictureNumber);
    EEPROM.commit();
  }
  file.close();
  esp_camera_fb_return(fb);
  
  delay(1000);
  
  // Turns off the ESP32-CAM white on-board LED (flash) connected to GPIO 4
  pinMode(4, OUTPUT);
  digitalWrite(4, LOW);
  rtc_gpio_hold_en(GPIO_NUM_4);

  esp_sleep_enable_ext0_wakeup(GPIO_NUM_13, 1);
 
  Serial.println("Going to sleep now");
  delay(1000);
  esp_deep_sleep_start();
  Serial.println("This will never be printed");
} 
 
void loop() {
 
}

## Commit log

2024-03-26 Uploaded current schematics
    [KIBO V1.kicad_pcb, KIBO V1.kicad_sch]
2024-03-26 Cleaned up schematics
    In order to upload them again with a corrected gitignore
    [KIBO V1.kicad_pcb, KIBO V1.kicad_sch]
2024-03-26 Updated .gitignore for KiCAD
2024-03-26 Re-uploaded KiCAD schematics and libraries
    [KIBO V1.kicad_pcb, KIBO V1.kicad_sch]
2024-04-04 feat: added code folder with esp32 electronics tests
2024-04-05 feat: added tests for mcp23017 and limit switch
2024-04-06 feat: added RGB LEDs and ESP32-CAM with PIR to schematic
    [KIBO V1.kicad_sch]
2024-04-06 feat: added tests for the L298N DC motor controller
2024-04-10 feat: Uploaded Tibia Assembly V3
2024-04-19 feat: Uploaded Tibia Assembly V5.f3d
    Uploaded the latest version with stetical improvements, and better attachment of the servo.
2024-04-19 feat: Uploaded Tibia Assembly
    Added TPU elements to cushion impacts, modified the tibia structure to fit said part
2024-04-22 feat: Uploaded Tibia Assembly.f3d
    Fixed sliding joint problems, added spacers for the servo back plate, M3 nuts, bolts and washers
2024-04-25 feat: Added femur to Tibia Assembly
    Added new femur
2024-04-25 feat: added tests for fan and RBG led control
2024-04-26 feat: added ESP32-CAM tests
2024-06-09 feat: corrected schematics, finished all footprints and checked ERC
    [KIBO V1.kicad_pcb, KIBO V1.kicad_sch]
2024-06-12 feat: created PCB power pins for ESP32cam and added battery measurement script
    [KIBO V1.kicad_sch]
2024-06-12 feat: added buttons test
2024-06-17 feat: Started working on the frame
2024-06-18 feat: added internal temp and hc-sr04 esp32cam test
2024-06-18 feat: added push buttons, batt measu and hc-sr04 esp32cam to schematic and footprints
    [KIBO V1.kicad_pcb, KIBO V1.kicad_sch]
2024-06-20 feat: setup PCB size, holes and all U components
    [KIBO V1.kicad_pcb]
2024-06-21 feat: final position of all footprints on PCB
    [KIBO V1.kicad_pcb]
2024-06-22 fix: cleaned footprint placement, text and logos
    [KIBO V1.kicad_pcb, KIBO V1.kicad_sch]
2024-06-22 feat: finished PCB and its CAD
    [KIBO V1.kicad_pcb, KIBO V1.kicad_sch, KIBO V1.step]
2024-06-24 feat: added latest tibia assembly and stl files for printable parts
    Fixed the pivot holes for the servo back plates (9,2 mm diameter) and discarded the parts named Ring, added a temporary m3 hole in the tibia as a slide stopper
    [Coxa1.stl, Coxa2.stl, Femur1.stl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]
2024-06-26 fix: added polarity sign to battery pads
    [KIBO V1.kicad_pcb]
2024-06-27 feat: Created the Kibo Assembly.f3d file
    Created the Kibo Assembly.f3d file as substitution of the file Kibo v9.f3d, which im not deleting in case victor messes up the github again.
2024-06-27 fix: we only store .stl and .step files, .f3d files under request to Alvi
2024-06-28 fix: deleted all old stl files
    Deletes all the older stl files due to the bad orientation of the parts
    [Coxa1.stl, Coxa2.stl, Femur1.stl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]
2024-06-28 feat: Uploaded the fixed stl files
    As per Victor´s request the STLs have been fixed, hopefully he enjoys them.
    [Bushing.stl, Coxa1.stl, Coxa2.stl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]
2024-07-02 feat: added calibration parts stls
    [calibration-arm.stl, calibration-ruler.stl]
2024-07-03 feat: added gerber files
    [KIBO V1-B_Cu.gbr, KIBO V1-B_Mask.gbr, KIBO V1-B_Paste.gbr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]
2024-07-03 fix: Modified coxa, femur and tibia slider
    Uploaded the modified versions of said parts, the slider gets a slightly bigger hole, the femur and coxa get smaller holes for the servo horn´s screws, going from 1.5 to 1.4 mm
    [Coxa1.stl, Coxa2.stl, Femur1.stl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]
2024-07-19 fix: Corrected al the parts as Viktor requested
    Went back to the first Serbo back plate and ring set up from the chipo github, the corrections mentioned include: tibia slider hole enlargement (sus), tibia support less design, servo back plate hole enlargement to house the ring used in chipo (mega sus) and modified all the pieces neccesary to fit ze ring
    [Bushing.stl, Coxa1.stl, Coxa2.stl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]
2024-07-20 Fix: ServoBackPlate thickness fix
    reduced thicknes of the backplate at the top to leave a safe amount of space, and reduced thickness at the bottom so that it works as intended and it touches the servo
    [ServoBackPlate.stl]
2024-08-03 feat: Uploaded final stl versions, mirror stls included
    [Coxa Left MIRROR.stl, Coxa Left.stl, Coxa Right MIRROR.stl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]
2024-08-09 Fix: Delted incorrect femur stl´s
    [Femur Left MIRROR.stl, Femur Left.stl, Femur Right MIRROR.stl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]
2024-08-09 Feat: Added remaining final parts
    [Back Armor.stl, Battery holder.stl, Bottom Armor.stl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]
2024-09-04 feat: created the URDF Models folder and uploaded URDF V1
    [Coxa_1_1.stl, Coxa_2_1.stl, Coxa_3_1.stl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]
2024-09-05 fix: deleted old frame and armor stlf files and mirror files
    Frame and armor files will be updated, mirror files will no longer be used as they are not needed, the user can mirror the stl files inside Cura or any other slider programs.
    [Back Armor.stl, Bottom Armor.stl, Coxa Left MIRROR.stl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]
2024-09-05 feat: uploaded final versions of body armor a driver spacers
    Final fixxes for the Body Armor top and bottom, the driver spacer lenght got also corrected and a purely cosmeticall part for the body armor is included(Body Armor Spoiler)
    [Body Armor Spoiler.stl, Bottom Body Armor Left.stl, Bottom Body Armor Right.stl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]
2024-09-05 fix: reorganized directories
    [Coxa_1_1.stl, Coxa_2_1.stl, Coxa_3_1.stl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]
